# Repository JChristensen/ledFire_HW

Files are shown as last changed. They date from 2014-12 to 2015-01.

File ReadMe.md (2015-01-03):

# LED PWM Fire Effect (Hardware Design)#
http://github.com/JChristensen/ledFire_HW  
ReadMe file  
Jack Christensen Dec 2014

## Introduction ##

A small project to simulate the appearance of a candle or other small fire using pulse width modulation and an ATtiny84A microcontroller. The original application of this project was to light a Halloween jack-o-lantern.

[Here](https://vimeo.com/110424346) is a video.  
Firmware is available [on GitHub](http://goo.gl/VueLrD).  
PC boards can be ordered [from OSH Park](https://www.oshpark.com/shared_projects/ASV7G4qa).  
A Bill of Materials with Mouser part numbers is part of this repo.

## Circuit Details ##

The circuit is meant to run on two AA cells; either alkaline or rechargeable types (NiMH, NiCd) will work. Battery life with two fresh alkaline cells is over 50 hours continuous with three LEDs installed on the board. The board is sized to fit on the back of a Keystone no. 2462 battery holder.

I use high-brightness LEDs with clear lenses. I only populate three LEDs, two yellow and one red. This worked well for my application. Adding the fourth LED will reduce battery life somewhat but the MCU has four PWM outputs so it is there as an option (the firmware drives all four).

The circuit uses a boost regulator to keep the supply voltage and therefore the LED brightness constant as the battery ages. By default, the regulator supplies 3.3V, but this can be changed to 5V via a solder jumper.

The MCU monitors the supply voltage and once the battery has been exhausted to the point where the regulator cannot supply the proper voltage, the MCU shuts down the circuit and goes into low-power sleep mode. The MCP1640 boost regulator has the ability to operate with less than one volt input; this can drain the battery to the point where the cells leak, so the shutdown mechanism is implemented in an effort to prevent this.

The cutoff voltage for the shutdown is selected by another solder jumper; the board is strapped for a 3V cutoff by default (to correspond to the regulator being set for 3.3V). If the regulator is changed to 5V, the cutoff should be changed to 4.5V using the jumper. Having said that, I see little use for operating the circuit with a 5V supply voltage as it will reduce battery life, but it was easy enough to implement at no extra cost (well, one resistor). A 5V supply will also likely require different values for the LED current-limiting resistors.

## CC BY-SA ##
"LED PWM Fire Effect" by Jack Christensen is licensed under [CC BY-SA 4.0](http://creativecommons.org/licenses/by-sa/4.0/).

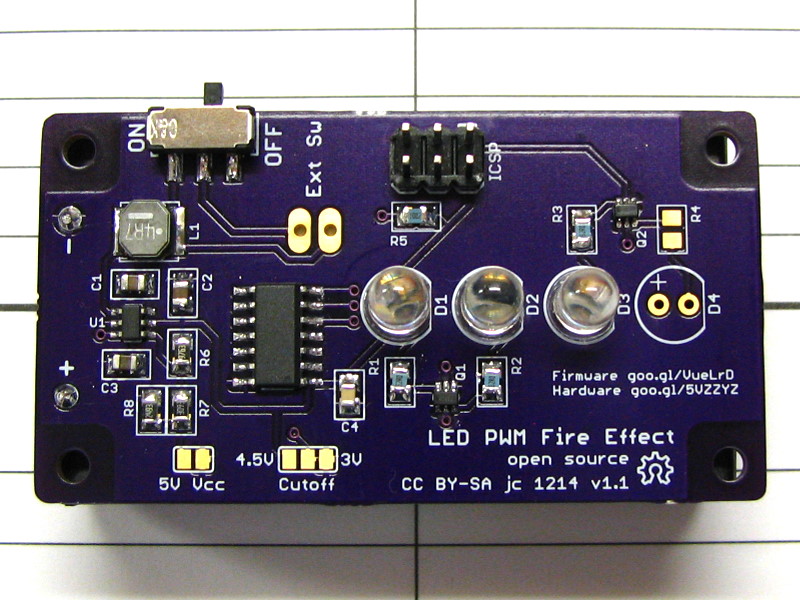
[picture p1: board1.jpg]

  
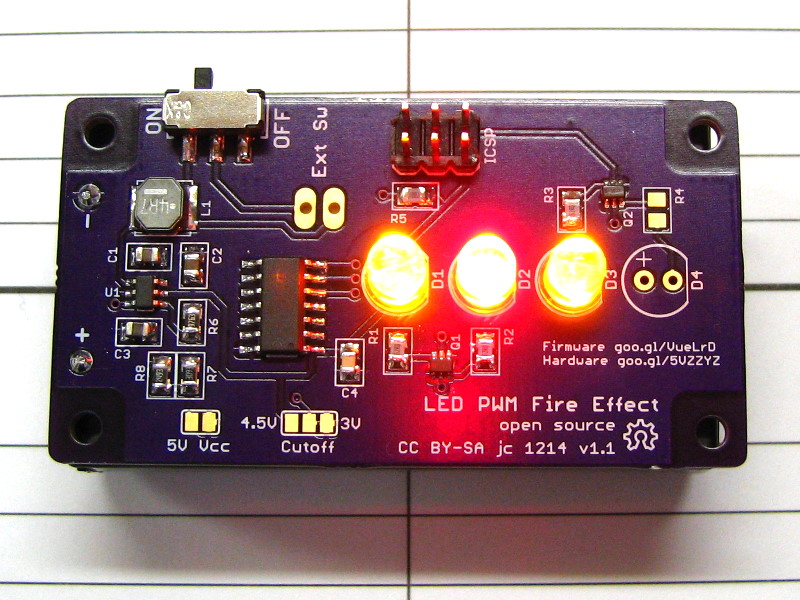
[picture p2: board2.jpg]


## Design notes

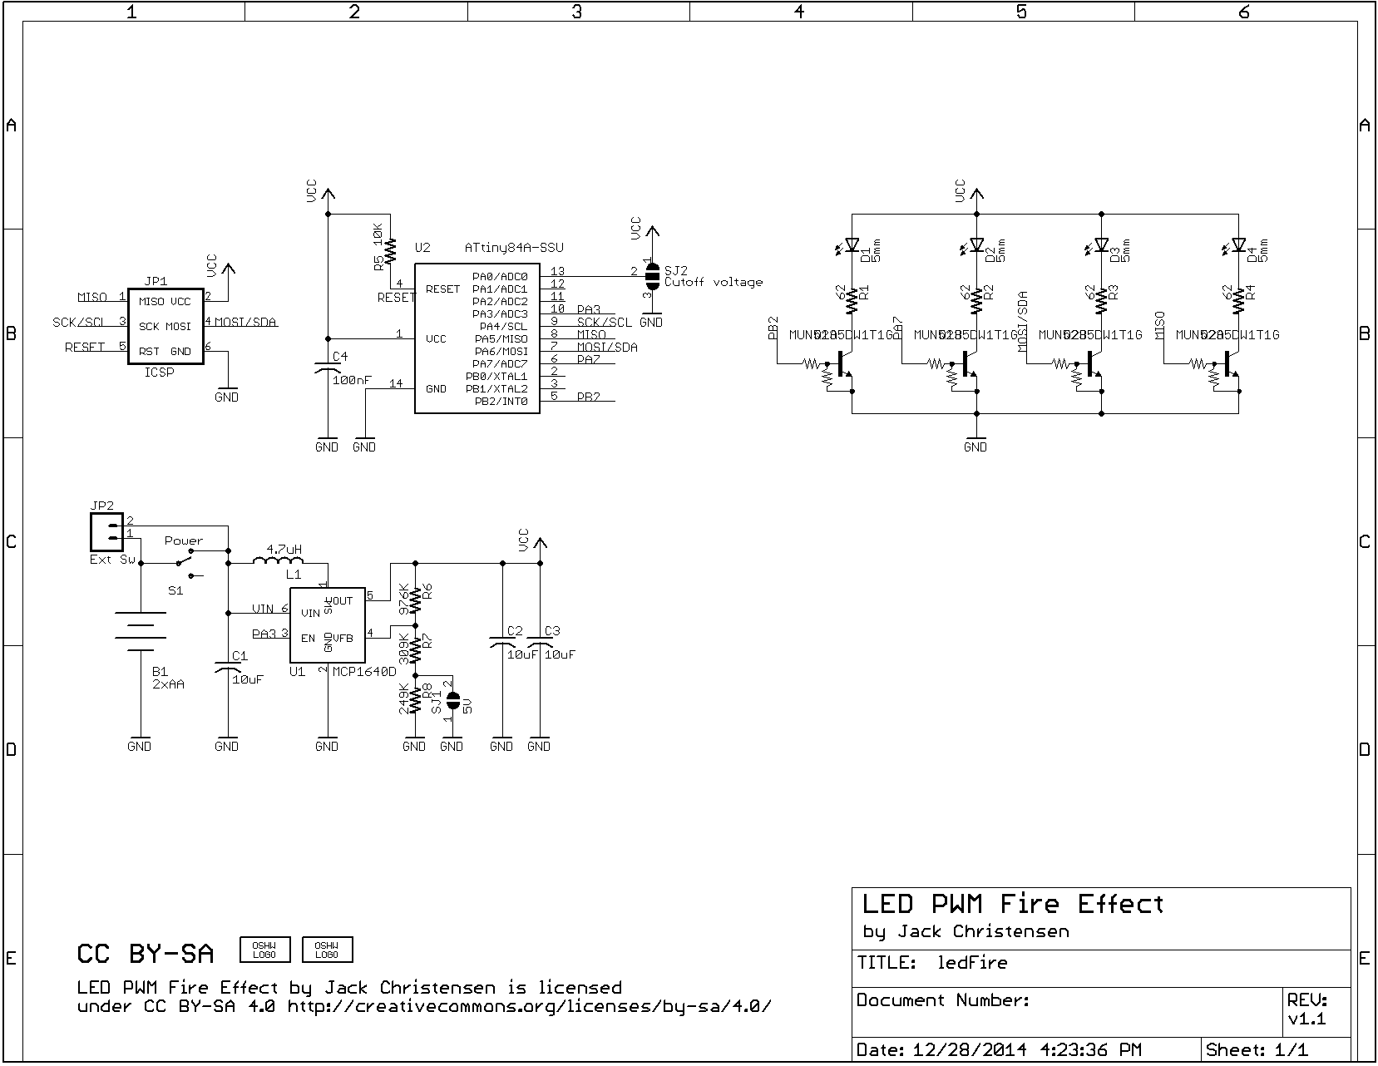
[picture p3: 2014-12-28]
schematic.png

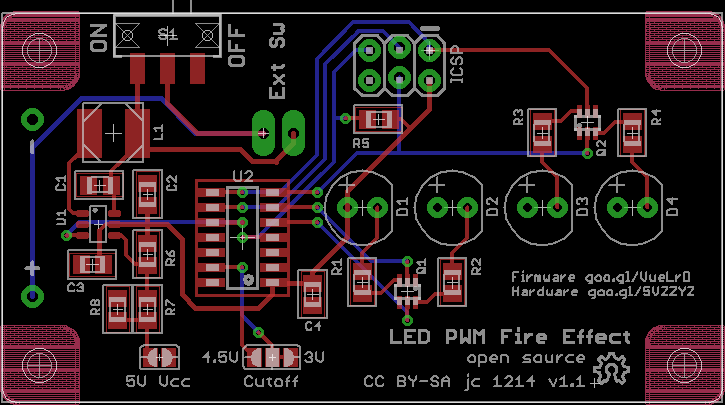
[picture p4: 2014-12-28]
board.png

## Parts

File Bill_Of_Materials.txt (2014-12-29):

LED PWM Fire Effect
Bill of Materials
Jack Christensen Dec 2014

Part    Value            Package             Mouser Part No.
B1      2xAA             Keystone 2462       534-2462
C1      10uF             M0805               81-GRM21BR71A106KA3L
C2      10uF             M0805               81-GRM21BR71A106KA3L
C3      10uF             M0805               81-GRM21BR71A106KA3L
C4      100nF            M0805               581-08055C104K
D1      Yellow           LED5MM              859-LTL2H3PYK14
D2      Red              LED5MM              859-LTL2H3EZ1K
D3      Yellow           LED5MM              859-LTL2H3PYK14
D4      DNP              LED5MM              (Do Not Populate)
JP1     ICSP                                 (Common Headers)
JP2     Ext Sw                               (Optional External Switch)
L1      4.7uH            4mm x 4mm           963-NRS4018T4R7MDGJ
Q1      MUN5235DW1T1G    SOT363              863-MUN5235DW1T1G
Q2      MUN5235DW1T1G    SOT363              863-MUN5235DW1T1G
R1      62               M0805               660-RK73H2ATTD62R0F
R2      62               M0805               660-RK73H2ATTD62R0F
R3      62               M0805               660-RK73H2ATTD62R0F
R4      62               M0805               660-RK73H2ATTD62R0F
R5      10K              M0805               660-RK73H2ATTD1002F
R6      976K             M0805               660-RK73H2ATTD9763F
R7      309K             M0805               660-RK73H2ATTD3093F
R8      249K             M0805               660-RK73H2ATTD2493F
S1      Power            C&K JS102011SAQN    611-JS102011SAQN
SJ1     5V               Solder Jumper       (N/A)
SJ2     Cutoff voltage   Solder Jumper       (N/A)
U1      MCP1640D         SOT23-6             579-MCP1640DT-I/CHY
U2      ATtiny84A-SSU    SO14                556-ATTINY84A-SSU

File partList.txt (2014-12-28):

Partlist

Exported from ledFire.sch at 12/28/2014 4:38:38 PM

EAGLE Version 6.4.0 Copyright (c) 1988-2013 CadSoft

Assembly variant: 

Part     Value          Device                Package                Library  Sheet

B1       2xAA           BATTERY-2AANOHOLES    KEYSTONE-2462-NO-HOLES _jc      1
C1       10uF           C-USM0805             M0805                  _jc      1
C2       10uF           C-USM0805             M0805                  _jc      1
C3       10uF           C-USM0805             M0805                  _jc      1
C4       100nF          C-USM0805             M0805                  _jc      1
D1       5mm            LED5MM                LED5MM                 _jc      1
D2       5mm            LED5MM                LED5MM                 _jc      1
D3       5mm            LED5MM                LED5MM                 _jc      1
D4       5mm            LED5MM                LED5MM                 _jc      1
JP1      ICSP           AVR_SPI_PRG_62X3_LOCK 2X3_LOCK               _jc      1
JP2      Ext Sw         M02                   1X02_LONGPADS          SparkFun 1
L1       4.7uH          INDUCTORNRS5020       NRS5020                _jc      1
Q1       MUN5235DW1T1G  MUN52XXSOT363         SOT363_PHILIPS         _jc      1
Q2       MUN5235DW1T1G  MUN52XXSOT363         SOT363_PHILIPS         _jc      1
R1       62             R-US_M0805            M0805                  _jc      1
R2       62             R-US_M0805            M0805                  _jc      1
R3       62             R-US_M0805            M0805                  _jc      1
R4       62             R-US_M0805            M0805                  _jc      1
R5       10K            R-US_M0805            M0805                  _jc      1
R6       976K           R-US_M0805            M0805                  _jc      1
R7       309K           R-US_M0805            M0805                  _jc      1
R8       249K           R-US_M0805            M0805                  _jc      1
S1       Power          SWITCH-SPSTSMD2       SWITCH-SPDT-SMD        SparkFun 1
SJ1      5V             SJ                    SJ                     jumper   1
SJ2      Cutoff voltage SJ2W                  SJ_2                   jumper   1
U1       MCP1640D       MCP1640               SOT23-6                _jc      1
U2       ATtiny84A-SSU  ATTINYX4SO14          SO14                   _jc      1

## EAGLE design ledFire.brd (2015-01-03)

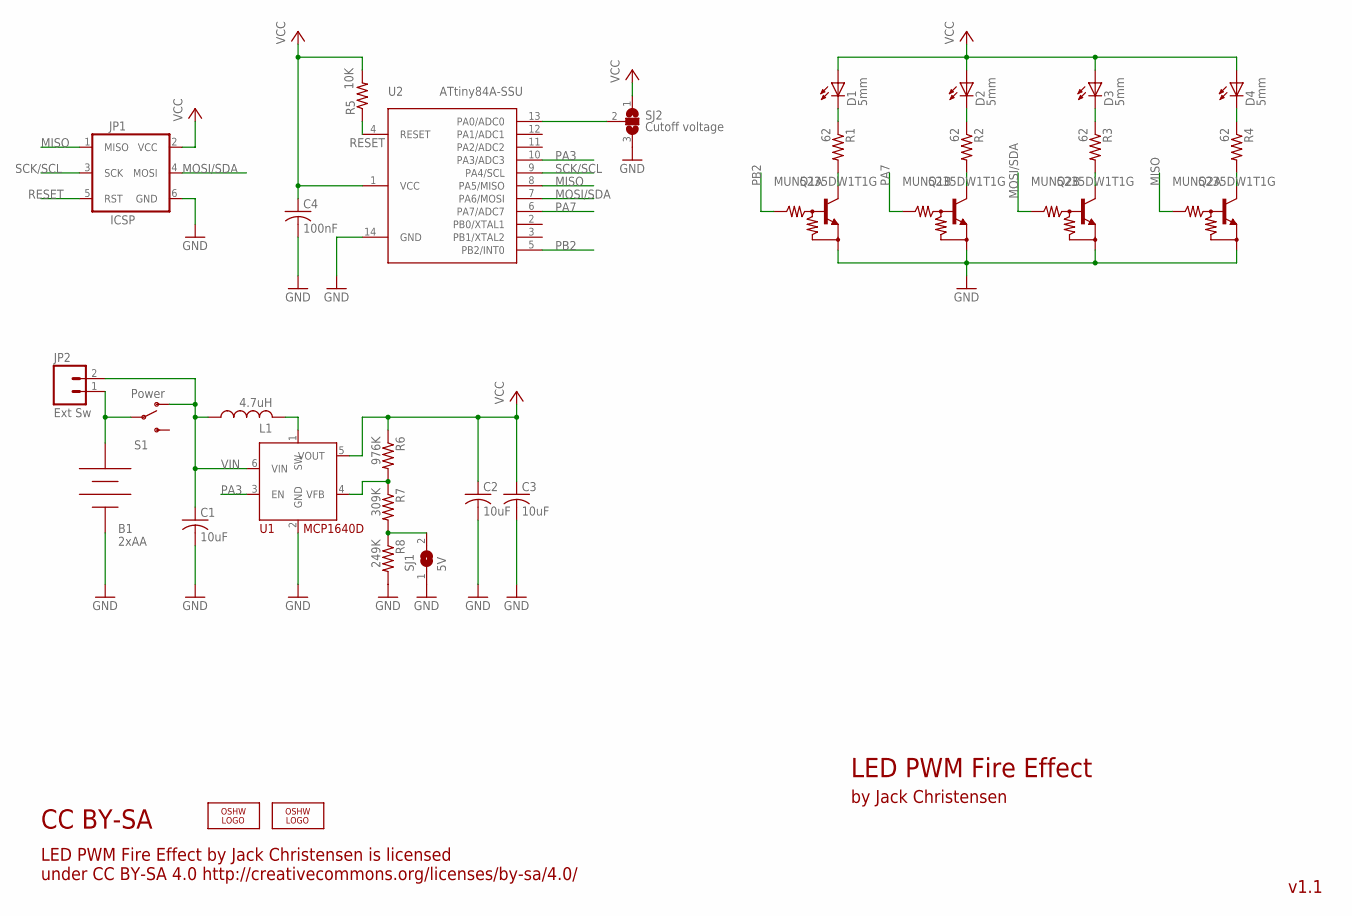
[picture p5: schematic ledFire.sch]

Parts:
B1: 2xAA; KEYSTONE-2462-NO-HOLES
C1, C2, C3: 10uF; M0805
C4: 100nF; M0805
D1, D2, D3, D4: 5mm; LED5MM
JP1: ICSP; 2X3_LOCK
JP2: Ext Sw; 1X02_LONGPADS
L1: 4.7uH; NRS5020
LOGO1, LOGO2: OSHW_LOGO_8MILX0100-NT; OSHW_8X100_NOTEXT
Q1, Q2: MUN5235DW1T1G; SOT363_PHILIPS
R1, R2, R3, R4: 62; M0805
R5: 10K; M0805
R6: 976K; M0805
R7: 309K; M0805
R8: 249K; M0805
S1: Power; SWITCH-SPDT-SMD
SJ1: 5V; SJ
SJ2: Cutoff voltage; SJ_2
U1: MCP1640D; SOT23-6
U2: ATtiny84A-SSU; SO14

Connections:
GND: B1.NEG, C1.2, C2.2, C3.2, C4.2, JP1.6 (GND), Q1.1 (E), Q1.4 (E), Q2.1 (E), Q2.4 (E), R8.2, SJ1.1, SJ2.3, U1.2 (GND), U2.14 (GND)
MISO: JP1.1 (MISO), Q2.5 (B), U2.8 (PA5/MISO)
MOSI/SDA: JP1.4 (MOSI), Q2.2 (B), U2.7 (PA6/MOSI)
unnamed: D1.K (C), R1.1
unnamed: R6.2, R7.1, U1.4 (VFB)
unnamed: D2.K (C), R2.1
unnamed: Q2.6 (C), R3.2
unnamed: Q1.3 (C), R1.2
unnamed: R7.2, R8.1, SJ1.2
unnamed: L1.P$2 (2), U1.1 (SW)
unnamed: Q1.6 (C), R2.2
unnamed: Q2.3 (C), R4.2
unnamed: B1.POS, JP2.1, S1.2
unnamed: SJ2.2, U2.13 (PA0/ADC0)
unnamed: D4.K (C), R4.1
unnamed: D3.K (C), R3.1
PA3: U1.3 (EN), U2.10 (PA3/ADC3)
PA7: Q1.2 (B), U2.6 (PA7/ADC7)
PB2: Q1.5 (B), U2.5 (PB2/INT0)
RESET: JP1.5 (RST), R5.1, U2.4 (RESET)
SCK/SCL: JP1.3 (SCK), U2.9 (PA4/SCL)
VCC: C2.1, C3.1, C4.1, D1.A, D2.A, D3.A, D4.A, JP1.2 (VCC), R5.2, R6.1, SJ2.1, U1.5 (VOUT), U2.1 (VCC)
VIN: C1.1, JP2.2, L1.P$1 (1), S1.1 (O), U1.6 (VIN)

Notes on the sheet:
LED PWM Fire Effect
by Jack Christensen
LED PWM Fire Effect by Jack Christensen is licensed under CC BY-SA 4.0 http://creativecommons.org/licenses/by-sa/4.0/
CC BY-SA
v1.1

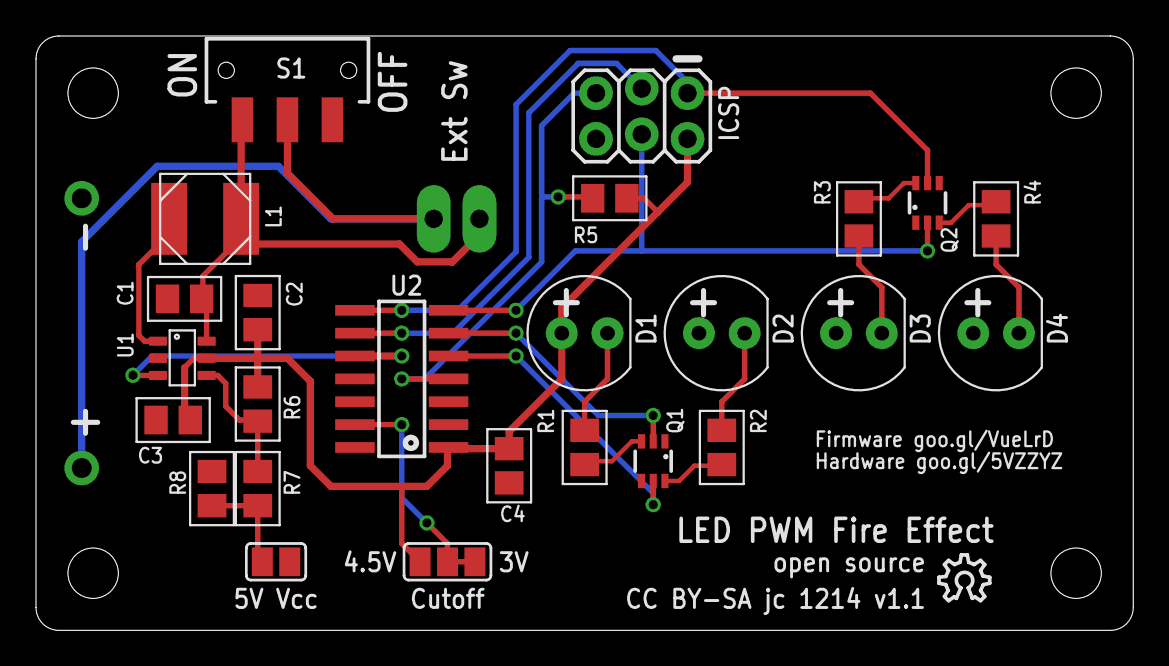
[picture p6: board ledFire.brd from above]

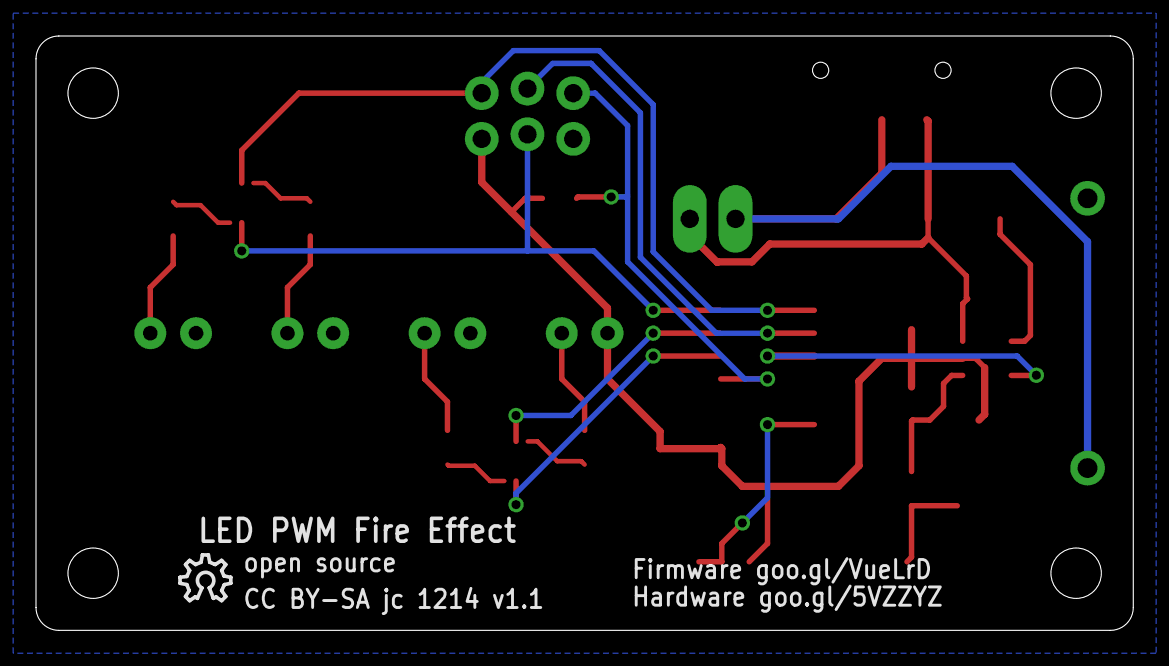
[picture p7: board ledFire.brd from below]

Board: 2 copper layers, 61.0 x 33.0 mm, 29 parts (2 on the bottom side), 23 nets.

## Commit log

2014-11-22 Initial commit.
    [ledFire.brd, ledFire.sch]
2014-12-23 v1.1, board corrections.
    [ledFire.brd, ledFire.sch]
2014-12-23 Update board and schematic images.
    [ledFire.brd, ledFire.sch]
2014-12-23 Update part list.
    [ledFire.sch]
2014-12-24 Tweak SOT363 footprint.
    [ledFire.brd, ledFire.sch]
2014-12-24 Tweak switch footprint.
    [ledFire.brd, ledFire.sch]
2014-12-28 Minor adjustments to a couple labels and one trace.
    [ledFire.brd]
2014-12-28 Update schematic and board images.
2014-12-29 Add Bill of Materials.
2015-01-03 Modified SOT-363 footprint, again. Update comment re battery life.
    [ledFire.brd, ledFire.sch]

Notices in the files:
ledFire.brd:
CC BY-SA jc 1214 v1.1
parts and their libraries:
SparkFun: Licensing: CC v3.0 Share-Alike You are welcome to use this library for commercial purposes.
